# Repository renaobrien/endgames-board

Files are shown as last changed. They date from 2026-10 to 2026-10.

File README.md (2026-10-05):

# Endgames Board

An open-source touchscreen chess board you can print and build at home. It plays your live games from [endgam.es](https://endgam.es) in full color, with your custom piece set on the board.

> Status: early. The reference board is built and paired, and firmware runs on it with over-the-air updates. The case (v0 STLs) is not test-fit yet and has no battery bay. The build guide is a draft.

## How it works

1. The board shows a 6-character pairing code.
2. You enter the code at endgam.es/board/pair while signed in.
3. The board picks up your current game. Tap a piece, tap where it goes.

Your opponent can be on the web, the app, or another board. Games against the in-app AI stay in the app.

## What's in this repo

| Folder | What it holds |
|---|---|
| [`docs/`](docs/) | Build guide |
| [`hardware/`](hardware/) | Printable case files (STL/3MF), source CAD, print settings |
| [`electronics/`](electronics/) | Parts list and wiring |
| [`firmware/`](firmware/) | Code that runs on the board |
| [`protocol/`](protocol/) | The device API the board uses to talk to endgam.es |

## Licenses

- Hardware (case, CAD, wiring, parts list): [CERN-OHL-S v2](LICENSE-HARDWARE)
- Firmware and code: [MIT](LICENSE)
- The Endgames name and logo: see [TRADEMARK.md](TRADEMARK.md)

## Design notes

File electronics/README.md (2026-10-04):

# Electronics

## Parts list (reference build)

| Part | Qty | Notes |
|---|---|---|
| Elecrow CrowPanel Advanced 5" ESP32-P4 HMI (800x480 IPS touch) | 1 | Controller, screen, touch and Wi-Fi in one |
| USB-C cable + 5V/2A power supply | 1 | Power and flashing |
| LiPo battery with PH2.0 plug | optional | For cordless play; the board charges it |

Wiring diagrams get added here if the build needs anything beyond the all-in-one board.

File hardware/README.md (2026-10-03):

# Hardware

Case files for the reference build: STL/3MF for printing, plus source CAD so you can modify it.

Each file gets listed here with its print settings (material, layer height, infill, supports) once it fits the reference board.

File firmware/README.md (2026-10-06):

# Firmware

Runs on the Elecrow CrowPanel Advanced 5" ESP32-P4 (800x480, GT911 touch). ESP-IDF + LVGL 9. Wi-Fi comes through the onboard ESP32-C6 (ESP-Hosted).

**Status:** compiles for the ESP32-P4 with ESP-IDF v5.5.1 (verified 2026-10-04). `main/bsp.c` brings up the screen, touch, backlight and Wi-Fi using the pins and timings from Elecrow's published sources for this board. Runs on the real board; over-the-air releases 0.8.0 to 0.12.0 have shipped and two consoles are paired.

## Known issue: Wi-Fi chip startup on early P4 boards

Boards with ESP32-P4 silicon v1.x (the boot log says `chip revision: v1.3`) can crash in a loop while ESP-Hosted starts the C6 Wi-Fi chip, before `app_main` (`assert failed: vApplicationGetIdleTaskMemory` or `esp_startup_start_app`). It hit the reference board on 2026-10-05 with firmware that had worked the day before. Fixed in 0.11.4 (0.11.5 for the full fix) by keeping ESP-Hosted's transport buffers in PSRAM (`CONFIG_ESP_HOSTED_MEMPOOL_PREFER_SPIRAM`) and running the SDIO link at 20 MHz. PSRAM stays at 200 MHz: at 80 MHz the RGB panel cannot read its frame buffer fast enough and the picture drifts sideways. Background: Elecrow CrowPanel 5" P4 issue #3, esp-hosted #657, esp-hosted-mcu #167. The C6 still runs its factory ESP-Hosted firmware, which is older than the host side; updating it over SDIO is the longer-term fix.

## Layout

| Path | What |
|---|---|
| `main/ui_game.c` | Game screen: 480x480 board, 320 px panel, tap to move, promotion picker, flip, menu |
| `main/ui_screens.c` | Wi-Fi setup, pairing, idle screens |
| `main/chess_pos.c` | FEN parsing, check detection, legal-move lookup. No LVGL |
| `main/api.c` | Device API client (`../protocol/API.md`) |
| `main/pieces_store.c` | Downloads the 12 piece PNGs from `board-pieces` into PSRAM |
| `main/store.c` | Wi-Fi and device token in NVS |
| `main/bsp.c` | Hardware bring-up: power rails, I2C, backlight MCU, 800x480 RGB panel, GT911 touch, Wi-Fi via the C6. The only hardware-specific file |
| `main/theme.h` | Generated colors. Do not edit |
| `main/fonts/` | Generated LVGL fonts (Sora, VT323, Bungee, all OFL) |
| `tools/preview/` | Desktop renderer for the screens |

## Colors and pieces come from the website

- `theme.h` is generated from the website's `src/styles/v2.css` by `npm run board:theme` in the endgames repo. Never hand-copy colors.
- Pieces come from the `board-pieces` endpoint, which resizes the same art the website draws.
- Fonts: `./fonts/build-fonts.sh` converts the TTFs in `fonts/src` (needs Node). OFL license files sit next to them.

## Preview on a desktop

```
cd firmware/tools/preview
./render.sh
```

Needs cmake, a C compiler and git. Writes PNGs to `docs/screenshots/`. The 12 piece PNGs in `tools/preview/pieces/` come from `npm run board:preview-pieces` (default set only).

## Build for the board

```
. $IDF_PATH/export.sh          # ESP-IDF v5.5.x
idf.py set-target esp32p4
idf.py build flash monitor     # board plugged into the UART0 USB-C
```

Versions that build: ESP-IDF v5.5.1, LVGL 9.2.2, esp_lvgl_port 2.6.x (newer esp_lvgl_port needs a newer IDF and LVGL).

Never commit Wi-Fi passwords or the device token. `main/secrets.h` and `.env*` are gitignored.

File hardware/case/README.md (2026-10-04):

# Case v0: flat brick

Two printed parts and four screws. Outer size 138.0 x 84.9 x 22.2 mm.

| File | What | Print |
|---|---|---|
| `case-tray.stl` | Back shell. Holds the board on 4 corner posts. Opening for the lower USB-C port (power), a slot for the power slider extender, microSD, and BOOT/RESET holes in the floor. The upper USB-C (UART0) stays closed: it's next to the slider and only needed for flashing, done with the case open | Floor down, no supports |
| `test-fit-tray.stl` | The tray with most of the floor cut out. Same walls, posts and openings. Print this first to check the USB-C ports, power switch, microSD and screw posts | Floor down, no supports. About 40% less plastic |
| `power-slider-extender.stl` | Clips onto the tiny power slider nub. Its tab sticks out the slot in the case side so you can switch the board on and off | Socket opening up, no supports |
| `case-lid.stl` | Front frame. Window matches the lit screen area, so no black border shows | Face down, no supports |

Hardware: 4 x M3 x 20 mm screws, from the back. They pass through the tray posts and the board's corner holes and bite into the lid's posts.

Source: `brick.py` (Python, trimesh). Change the numbers at the top and re-run to regenerate the STLs.

v0 limits:
- Port and button positions are estimated from a photo of the board with a ruler (about +/- 2 mm). Openings are oversized to allow for that.
- Hole positions are estimated too. Print `../test-fit-plate.stl` first.
- No battery bay yet.

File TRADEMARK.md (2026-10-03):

# Trademark

The code and hardware in this repo are open. The Endgames name and logo are not covered by those licenses.

You can:

- Build boards from this repo for yourself or as gifts.
- Modify the design and share your version.
- Say your board is "compatible with Endgames" or "based on the Endgames Board."

You can't, without written permission:

- Sell boards, kits, or cases under the Endgames name or logo.
- Use the Endgames name or logo in a way that suggests your product is official.

Questions: open an issue.

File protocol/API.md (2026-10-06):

# Endgames Board Device API, v1

Base URL: `https://endgam.es/.netlify/functions`

Every response carries the header `X-Endgames-Board-Api: 1`. Bodies are JSON.

## Pairing

The board shows a code. The owner types it on endgam.es. The board then receives a device token it keeps in flash.

### 1. Start: `POST /board-pair-start`

No auth, no body.

```json
200 { "code": "K7XQ2M", "pollSecret": "egp_...", "expiresAt": "2026-10-03T20:00:00Z", "claimUrl": "https://endgam.es/board/pair?code=K7XQ2M" }
429 { "error": "Too many pairing attempts" }
```

Show `code` as text and `claimUrl` as a QR code (and as text). The URL carries the code, so scanning it prefills the pairing page. Keep `pollSecret` private. Codes expire after 10 minutes.

### 2. Owner claims the code

The owner signs in at endgam.es and enters the code. The board does nothing in this step.

### 3. Poll: `POST /board-pair-poll`

```json
{ "pollSecret": "egp_..." }
```

```json
202 { "status": "pending" }
200 { "status": "paired", "deviceToken": "egb_...", "deviceId": "uuid" }
410 { "error": "Pairing expired. Start again." }
```

Poll every 3 seconds. `deviceToken` is returned once. Store it, then stop polling.

## Playing

Send the device token on every call:

```
Authorization: Bearer egb_...
```

A `401` means the token was revoked or is unknown. Wipe it and start pairing again.

### Get the current game: `GET /board-game`

Optional query: `?gameId=uuid` to fetch a specific game (any status).

```json
200 {
  "apiVersion": 1,
  "game": {
    "id": "uuid",
    "fen": "rnbqkbnr/pppppppp/8/8/4P3/8/PPPP1PPP/RNBQKBNR b KQkq - 0 1",
    "yourColor": "white",
    "turn": "black",
    "yourTurn": false,
    "status": "IN_PROGRESS",
    "moveCount": 1,
    "lastMove": { "from": "e2", "to": "e4", "san": "e4" },
    "moves": ["e4"],
    "legalMoves": [],
    "timeControl": "1d",
    "moveDeadline": "2026-10-07T19:30:00Z",
    "clock": null,
    "endReason": null,
    "opponent": { "name": "magnus_fan", "isAi": false, "difficulty": null, "pfpUrl": "https://.../avatar.png" },
    "updatedAt": "2026-10-03T19:30:00Z"
  }
}
```

`moves` is every move so far in SAN, oldest first (up to 500), for the move list.

**Time per move.** Games against people have one deadline per move. `timeControl` is `"1d"`, `"3d"` or `"1w"` (1 day, 3 days, 1 week per move), or `null` for a computer game. `moveDeadline` is the moment the player on the move loses on time, as an ISO 8601 UTC string. It is `null` when there is no deadline: computer games, finished games, and games started with a live clock (below). Every move resets the deadline for the player who moves next, so after your move `moveDeadline` is your opponent's, and the reverse. `yourTurn` tells you whose it is.

Show the time left in words, rounded down: `23 h left`, `2 days left`, `45 min left`; `1 day left` and `1 h left` in the singular. Count down to `moveDeadline` using the `Date` response header as "now" (or the device clock if it is set from the network): the deadline is a server time, and a day-long deadline tolerates a few minutes of skew. When 2 hours or less are left on your move, show a banner (the console has no speaker, so visual only). When the deadline passes, call `board-game` right away: the server settles the game and the response shows the result. The server gives a mover 1 second of grace for network delay.

If a first move is missed (white never moves, or black never replies to white's first move) the game ends as `ABANDONED` with no rating change. After that, a missed deadline is a loss on time, unless the other player cannot possibly checkmate, which is a draw.

**Live clocks (retired).** Games started before time per move existed carry a live clock and finish under their old rules: `timeControl` is one of `3+2`, `5+0`, `10+0`, `15+10`, `moveDeadline` is `null`, and `clock` is `{ "incrementMs", "yourMs", "opponentMs", "running" }`: the time each side has left at the moment of the response, with `running` set to `"you"`, `"opponent"` or `null`. Count down locally and replace the numbers on every response. No new game gets a live clock, so a firmware that only shows time per move can show nothing extra for these games, or keep its clock code until none are left.

`endReason` is `null` while the game is in progress. Afterwards it is one of `checkmate`, `draw` (stalemate and other draws), `resign`, `timeout`, `abandoned`. Games finished before clocks existed have `null`. A game lost on its deadline reads `timeout`.

`opponent.isAi` is true in games against the computer, with `difficulty` set (`beginner`, `intermediate`, `advanced`, `expert`; computer games started on the website before difficulty was stored read as `intermediate`). For people, `difficulty` is `null`.

`game` is `null` when there is nothing to play. `status` is one of `IN_PROGRESS`, `WHITE_WON`, `BLACK_WON`, `DRAW`, `ABANDONED`.

`legalMoves` lists your moves in UCI form (`e2e4`, `e7e8q`) when it's your turn, and is empty otherwise. Use it to highlight squares after a tap.

Polling: every 10 seconds while waiting for the opponent (every 5 seconds in a timed game), every 60 seconds when idle. Redraw only when `moveCount` or `status` changes.

### Make a move: `POST /board-move`

```json
{ "gameId": "uuid", "from": "e7", "to": "e5", "moveCount": 1 }
```

Add `"promotion": "q"` (`q`, `r`, `b`, or `n`) when a pawn reaches the last rank. `moveCount` is the value from your last `board-game` response.

```json
200 { "apiVersion": 1, "game": { ... } }
409 { "error": "Board is out of date", "apiVersion": 1, "game": { ... } }
409 { "error": "Not your turn", ... }
409 { "error": "Game is over", ... }
422 { "error": "Illegal move", ... }
```

Every `409` and `422` includes the current `game`. Redraw from it.

The server checks legality on every move. `legalMoves` is there so the board can show where a piece can go.

### Get piece images: `GET /board-pieces`

Optional query: `?gameId=uuid` to use the piece set you have in that game. Without it, the board gets your active set, or the default set if you have none.

```json
200 {
  "apiVersion": 1,
  "set": { "id": "uuid-or-default-hash", "name": "My set", "kind": "custom" },
  "size": 60,
  "pieces": {
    "wk": "https://.../board/<set>/wk.png", "bk": "https://.../board/<set>/bk.png",
    "wq": "...", "bq": "...", "wr": "...", "br": "...",
    "wb": "...", "bb": "...", "wn": "...", "bn": "...", "wp": "...", "bp": "..."
  }
}
502 { "error": "Could not prepare piece images" }
```

Twelve PNGs, 60x60, transparent background. Keys are color (`w`/`b`) plus piece (`k q r b n p`). Black pieces match the website: the same art darkened with a thin light halo. The URLs are public and permanent per set, so download once per set and cache on flash or SD. The first call for a set can take a few seconds while the server resizes and caches the images. Fetch again when `set.id` changes.

## Home, new games and sets (v1 additions)

The board is a full Endgames client: it starts games, lists them, and switches piece sets, the same as the website. These are additive v1 endpoints.

### Home screen: `GET /board-home`

One call for the home screen.

```json
200 {
  "apiVersion": 1,
  "profile": { "name": "deltajuliet", "pfpUrl": "https://.../avatar.png", "elo": 1240, "ranked": true,
               "wins": 31, "losses": 18, "draws": 3, "winRate": 60 },
  "games": [
    {
      "id": "uuid",
      "opponent": { "name": "queenbee", "isAi": false, "difficulty": null, "pfpUrl": "https://.../avatar.png" },
      "yourColor": "white",
      "yourTurn": true,
      "status": "IN_PROGRESS",
      "moveCount": 14,
      "timeControl": "1d",
      "moveDeadline": "2026-10-05T19:30:00Z",
      "yourMs": null,
      "opponentMs": null,
      "running": null,
      "updatedAt": "2026-10-04T19:30:00Z"
    }
  ],
  "incomingChallenges": [ { "id": "uuid", "from": { "name": "queenbee", "elo": 1820, "pfpUrl": "https://.../avatar.png" } } ],
  "activeSetId": "uuid-or-default",
  "sets": [ { "id": "uuid-or-default", "name": "Default", "kind": "default", "missing": false,
              "preview": { "wk": "https://.../wk.png", "wn": "https://.../wn.png" } } ]
}
```

Each list item carries `timeControl` and `moveDeadline` (same meaning as in `board-game`; both `null` for a computer game). `yourMs`, `opponentMs` and `running` are set only for games started with a live clock before time per move existed (same meaning as `clock` in `board-game`) and are `null` otherwise. Show "Your turn" or "Their turn", and the time left on the move next to it.

`games` holds your in-progress games (against people and the computer), your-turn first, then most recently updated, up to 20. You can have at most 20 in progress; `board-new-game` returns `429` above that. `incomingChallenges` lists direct challenges waiting for your answer (see `board-challenge-respond`). `sets` lists the built-in set plus sets you made. A set with `"missing": true` has pieces that no longer load (the images were saved with a link that expired): its `preview` is `null`, show "Pieces missing", and don't offer it as a choice (`board-set` answers `409` for it). It can still be renamed or deleted. `activeSetId` is never a missing set: if the active set's pieces are gone it reads `"default"`. Treat a missing `missing` field as `false`. `elo` is `null` and `ranked` false before the first ranked game.

`profile.wins`, `losses` and `draws` count your finished games. `winRate` is wins over all finished games as a whole percent (the number the website's You screen shows), and `null` before your first finished game, when the three counts are `0`. Older servers leave all four out: treat a missing field as no stats.

`pfpUrl` is the player's profile picture: a public https link to a 256x256 PNG for pictures set on the website (Account, Profile picture). It is `null` when the player has not set one, and always `null` for the computer. Old accounts may hold a picture from another site (often a JPEG), so check the content type before decoding. Cache by URL: a new picture gets a new URL.

### Start a game: `POST /board-new-game`

Against the computer:

```json
{ "mode": "ai", "difficulty": "beginner", "first": "me" }
```

`difficulty` is `beginner`, `intermediate`, `advanced` or `expert` (shown as Easy, Medium, Hard, Expert). `first` is `me`, `computer` or `random` (who moves first). The older `color` field (`white`, `black`, `random`) is still accepted. Returns `200 { "apiVersion": 1, "game": { ... } }` in the `board-game` shape. If the computer plays white, its first move is already made.

Challenge a friend:

```json
{ "mode": "challenge", "color": "random" }
```

Creates an open challenge with your active set. `color` is the color you play (`random` picks one). Add `"timeControl"`: `"1d"` (default), `"3d"` or `"1w"`, the time each player has per move. Returns:

```json
200 { "apiVersion": 1, "challenge": { "id": "uuid", "url": "https://endgam.es/?challenge=uuid", "expiresAt": "..." } }
```

The board shows `url` as a QR. When someone accepts, the game appears in `board-home` and `board-game`.

Challenge a specific player (find them with `board-users`):

```json
{ "mode": "challenge", "opponentId": "uuid", "first": "me", "timeControl": "3d" }
```

`timeControl` is `"1d"`, `"3d"` or `"1w"`, and `"1d"` when left out. Anything else is `400`. It is also `400` for computer games, which have no deadline. For consoles on older firmware, the old values (`3+2`, `5+0`, `10+0`, `15+10`, `"untimed"`, `null`) are accepted and become `"1d"`.

`first` is `me`, `computer` or `random`; here `computer` means the other player moves first. Returns:

```json
200 { "apiVersion": 1, "challenge": { "id": "uuid", "opponent": "queenbee", "expiresAt": "..." } }
```

`404` if the player does not exist or is the computer, `400` if you challenge yourself, `409` if you already have a pending challenge with that player. The other player sees it in their `board-home` `incomingChallenges` (and on the website's Play tab). Challenges expire after 48 hours.

### Find a player: `GET /board-users?q=`

Username search for "Challenge a player". `q` needs at least 3 characters (shorter returns an empty list).

```json
200 { "apiVersion": 1, "users": [ { "id": "uuid", "name": "queenbee", "elo": 1820 } ] }
```

At most 10, highest rating first. Excludes you and the computer.

### Answer a challenge: `POST /board-challenge-respond`

```json
{ "id": "challenge-uuid", "accept": true }
```

Accept returns `200 { "apiVersion": 1, "game": { ... } }` in the `board-game` shape. Decline returns `200 { "apiVersion": 1, "declined": true }`. Only the challenged player can respond: anything else is `404`. `409` means the challenge already expired, was answered, or was withdrawn: refresh `board-home`.

### Quick match: `POST` and `GET /board-quick-match`

Pairs you with the next waiting player. Every quick match is 1 day per move, so there is nothing to pick. A `timeControl` in the body is ignored (consoles on older firmware may still send one).

```json
POST { "action": "join" }    or    { "action": "cancel" }
```

Both `POST` and `GET` return the same shape:

```json
200 { "apiVersion": 1, "status": "waiting" }
200 { "apiVersion": 1, "status": "matched", "game": { ... } }
200 { "apiVersion": 1, "status": "idle" }
```

`join` pairs you with the oldest waiting player right away (`matched`), or queues you (`waiting`). Poll `GET` every 3 seconds while waiting. The first `GET` that returns `matched` delivers the `game` once and clears your queue row, so the next poll says `idle`. Queue entries last 5 minutes (then `idle`). Send `cancel` when the player backs out.

### Games against the computer

`board-game` and `board-game?gameId=` include computer games. After you move with `board-move`, the server makes the computer's reply before responding, so the returned `game` already includes it (or, if that takes longer than the request allows, the reply appears on the next `board-game` poll). Difficulty matches the website.

`sets[].preview` holds the white king and knight PNGs (the same 60x60 images `board-pieces` serves for that set) for the Sets tab.

### Leaderboard: `GET /board-leaderboard`

The same ranking the website shows, top 50.

```json
200 {
  "apiVersion": 1,
  "entries": [ { "rank": 1, "name": "queenbee", "elo": 1820, "isYou": false } ],
  "you": { "rank": 42, "elo": 1240 }
}
```

`you` is `null` before your first ranked game.

### Make a set

The board has no camera, so its Make tab shows a QR for `https://endgam.es/make`, which opens the website's Make tab (after sign-in) on the phone. New sets show up in `board-home`.

### Resign: `POST /board-resign`

```json
{ "gameId": "uuid" }
```

Returns the finished `game`. Resigning a game that's already over returns `409`.

### Switch piece set: `POST /board-set`

```json
{ "setId": "uuid-or-default" }
```

Sets your active set (the same one the website uses). `board-pieces` then returns it. `404` if the set doesn't exist or is deleted; `409` `{ "error": "Pieces missing" }` if the set's pieces no longer load (see `missing` in `board-home`).

### Rename or delete a set: `POST /board-set-edit`

```json
{ "setId": "uuid", "action": "rename", "name": "Vaporwave Rena" }
{ "setId": "uuid", "action": "delete" }
```

Only your own sets. `"default"` can't be edited.

- `rename`: `name` is trimmed, 1 to 32 characters.
- `delete`: hides the set (`is_hidden = true`), the same as deleting on the website, so it can be restored there. If it was your active set, your active set goes back to the default.

Returns `200 { "ok": true, "activeSetId": "uuid-or-default" }`. `404` if the set doesn't exist, is already deleted, or isn't yours. `400` for a bad body or name.

## Versioning

Breaking changes get a new version number and run alongside the old one for at least 6 months. Adding a new field doesn't count as breaking, so ignore fields you don't recognize.

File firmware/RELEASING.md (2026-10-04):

# Releasing board firmware

Boards check https://endgam.es/firmware/board.json at startup and every 6 hours between games.
If the version there is newer than theirs, they download the update, restart into it, and keep it
once it gets back online. If the new version crashes or can't get online, the board goes back to
the previous version on its next restart.

1. Bump the version
   - In `firmware/CMakeLists.txt`, raise `PROJECT_VER` (for example 0.8.0 to 0.9.0).
2. Build
   - `idf.py build`
3. Publish the update file
   - Copy `build/endgames_board.bin` to the Endgames site as `public/firmware/endgames-board-<version>.bin`.
4. Point boards at it
   - Update `public/firmware/board.json`:
     `{"version": "<version>", "url": "https://endgam.es/firmware/endgames-board-<version>.bin"}`
5. Deploy the site
   - Boards pick it up within 6 hours, or right away after a restart.

The USB flasher file (full image at 0x0) is made with
`python -m esptool --chip esp32p4 merge_bin -o endgames-board-v<version>.bin "@flash_args"` from `build/`.
Only needed for first installs; everything after that updates over Wi-Fi.

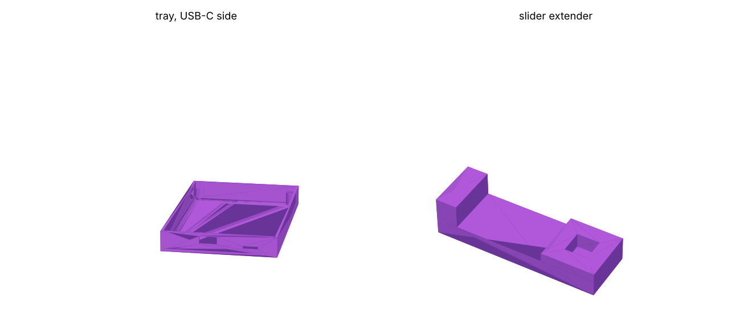
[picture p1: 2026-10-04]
hardware/case/slider-preview.png

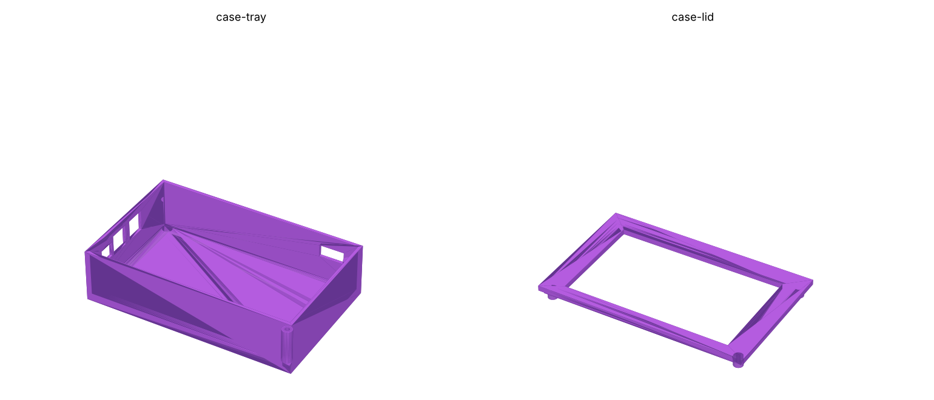
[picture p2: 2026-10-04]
hardware/case/case-preview.png

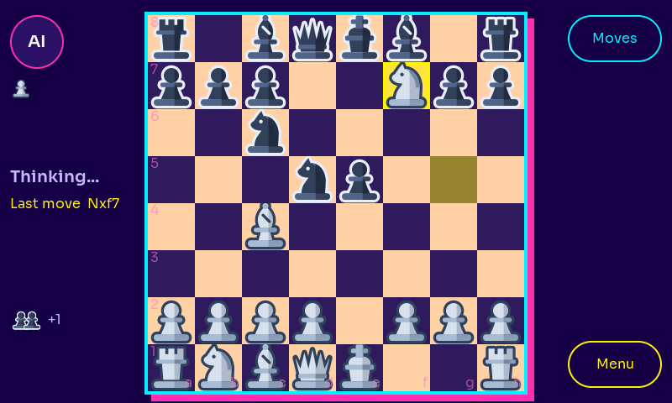
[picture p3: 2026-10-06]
docs/screenshots/board-game.png

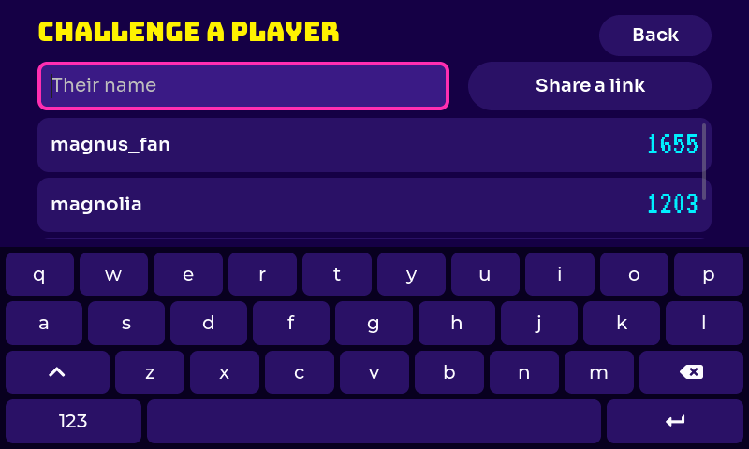
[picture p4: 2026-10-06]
docs/screenshots/board-find.png

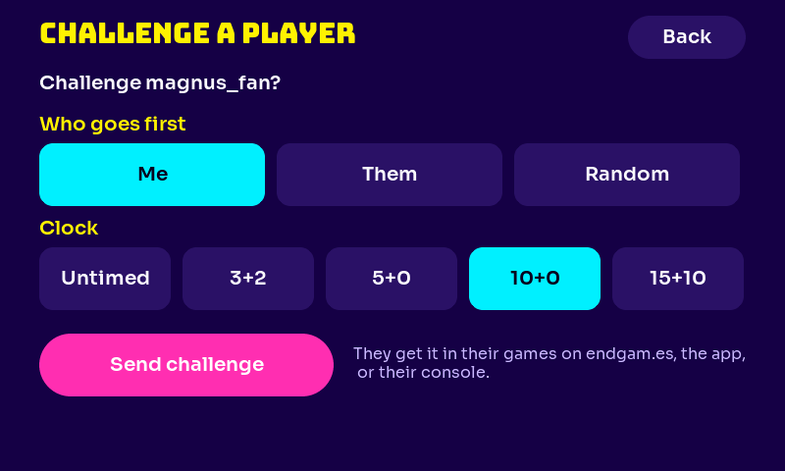
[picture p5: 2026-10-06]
docs/screenshots/board-find-confirm.png

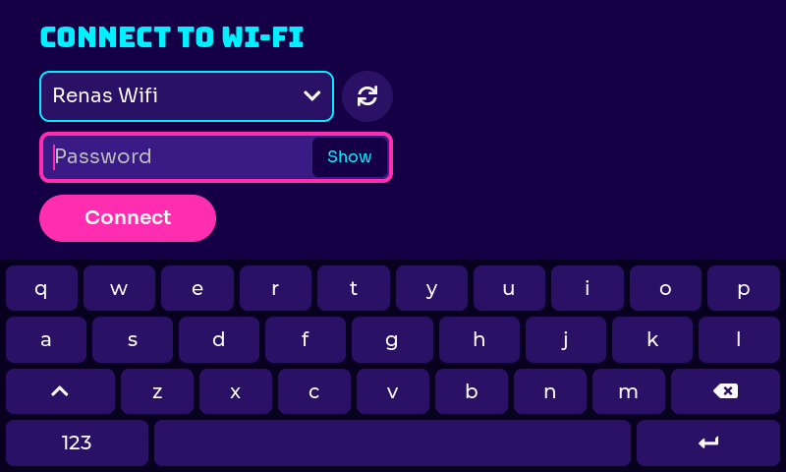
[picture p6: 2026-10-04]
docs/screenshots/board-wifi.png

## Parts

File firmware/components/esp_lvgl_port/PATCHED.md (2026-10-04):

# esp_lvgl_port 2.6.3, patched for Endgames

Upstream 2.6.3 only enables RGB panels on ESP32-S3 (`lvgl_port_add_disp_rgb` fails on the P4 with
"RGB is supported only on ESP32S3"). Elecrow ships the same kind of patch in their CrowPanel P4 factory code.

Change: the S3-only `#if` guards for the RGB header, the RGB vsync/bounce callback and
`lvgl_port_add_disp_rgb` also accept `CONFIG_IDF_TARGET_ESP32P4` (src/lvgl9/esp_lvgl_port_disp.c).
The avoid_tearing frame-buffer path is NOT patched (it calls the MIPI-DSI API on P4), so keep avoid_tearing off.
License: Apache-2.0 (upstream), see license.txt.

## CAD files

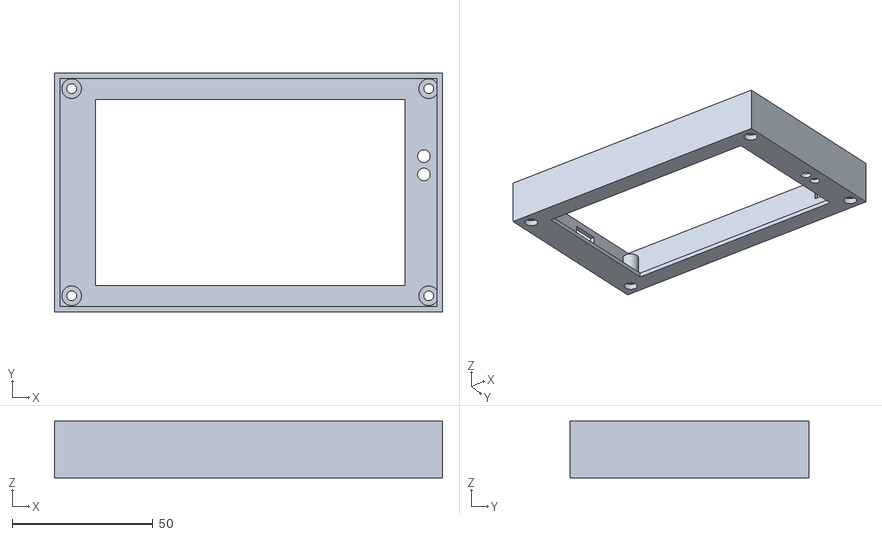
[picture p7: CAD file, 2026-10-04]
hardware/case/test-fit-tray.stl
138.0 x 84.9 x 20.2

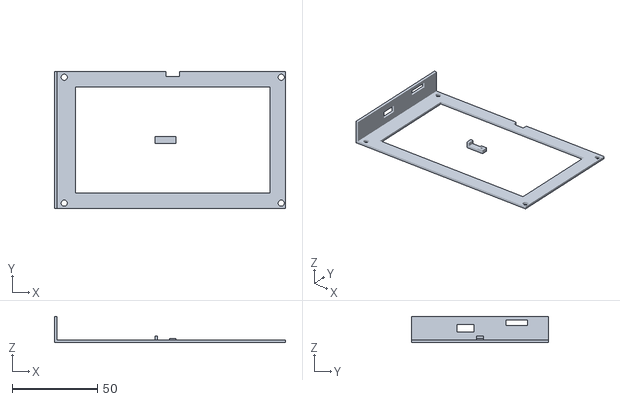
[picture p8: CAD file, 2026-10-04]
hardware/template.stl
135.2 x 80.1 x 15.5

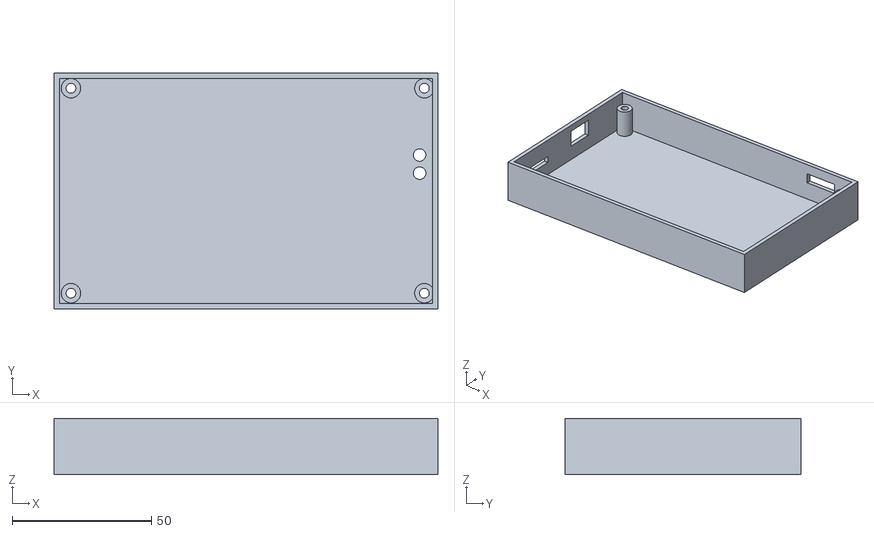
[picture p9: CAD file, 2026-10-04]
hardware/case/case-tray.stl
138.0 x 84.9 x 20.2

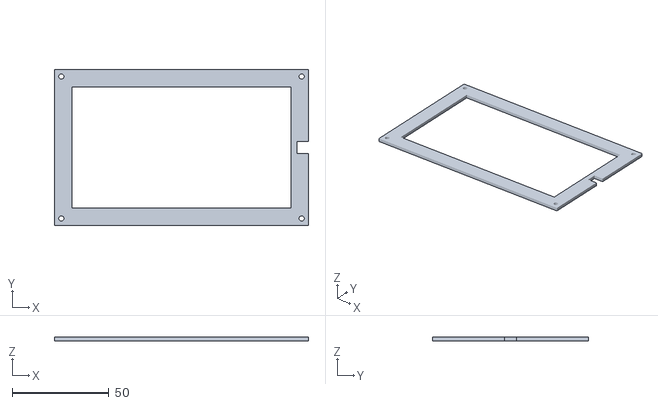
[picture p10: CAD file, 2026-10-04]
hardware/test-fit-plate.stl
131.0 x 80.2 x 2.00

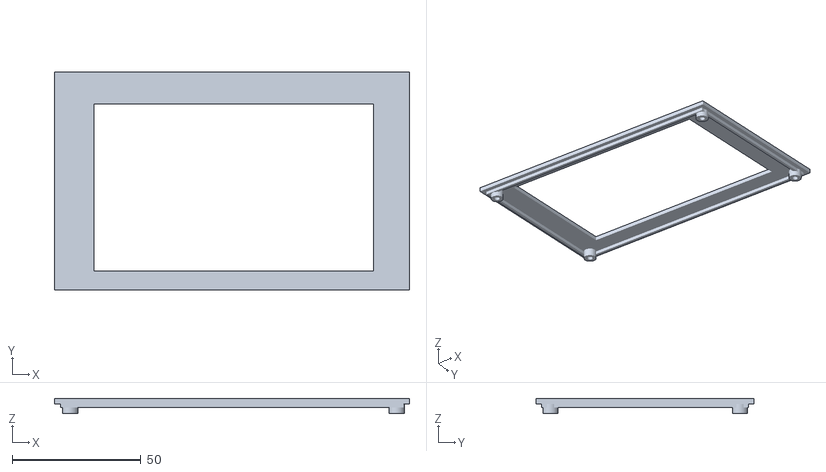
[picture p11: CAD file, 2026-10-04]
hardware/case/case-lid.stl
138.0 x 84.9 x 5.70

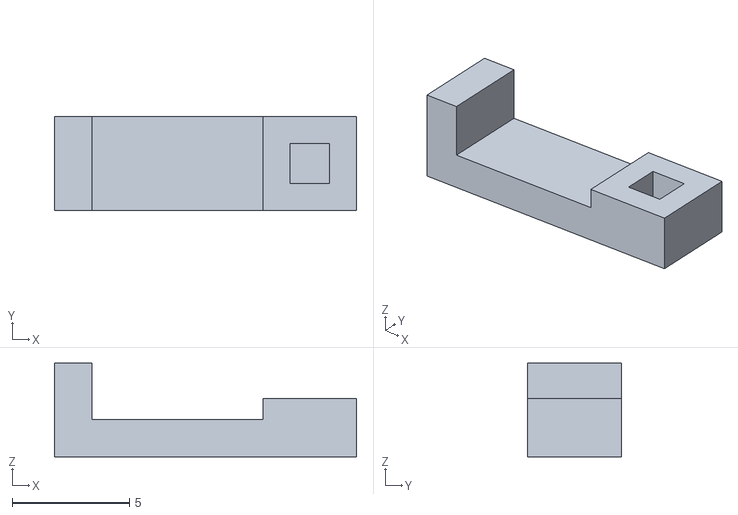
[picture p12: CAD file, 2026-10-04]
hardware/case/power-slider-extender.stl
12.9 x 4.00 x 4.00

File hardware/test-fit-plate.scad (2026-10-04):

// Endgames Board: test-fit plate for the CrowPanel Advanced 5" (ESP32-P4).
// Print it, lay the board on it face up, and check all 4 holes line up.
// Edit the numbers below if they don't, then the case uses the corrected values.
L = 131;       // board length, mm
W = 80.2;      // board width, mm (caliper)
T = 2;         // plate thickness
HOLE_D = 2.7;  // clearance for M2.5
HOLE_IN = 3.5; // hole center from each edge (estimated from photo)
BORDER = 9;    // frame width
NOTCH = 6;     // notch marks the USB-C edge

difference() {
  cube([L, W, T]);
  translate([BORDER, BORDER, -1]) cube([L - 2*BORDER, W - 2*BORDER, T + 2]);
  for (x = [HOLE_IN, L - HOLE_IN], y = [HOLE_IN, W - HOLE_IN])
    translate([x, y, -1]) cylinder(d = HOLE_D, h = T + 2, $fn = 40);
  translate([L - NOTCH/2, W/2 - NOTCH/2, -1]) cube([NOTCH, NOTCH, T + 2]);
}

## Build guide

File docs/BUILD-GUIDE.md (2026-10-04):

# Build Guide

Build a touchscreen chess board that plays your live games from [endgam.es](https://endgam.es), with your own piece set on it.

Each step says what I used, then what changes if you use something else.

> **Status:** the case and parts below are being test-printed on the reference board. The firmware is written but not yet running on real hardware. This guide gets updated as each part is confirmed.

## What you need

| Part | What I used | Notes |
|---|---|---|
| Screen + controller | Elecrow CrowPanel Advanced 5" ESP32-P4 HMI (SKU DHE04005D), 800x480 IPS touch, about $43 | Screen, touch, Wi-Fi and USB-C all on one board. No wiring |
| Power | USB-C cable and a 5V/2A USB power adapter | Plugs into the board's lower USB-C port |
| Screws | 4 x M3 x 20 mm | Hold the case together through the board's corner holes |
| Printer + filament | Any FDM printer, PLA | Nothing needs supports |
| Computer | Mac, Windows or Linux with a USB-C cable | Only for installing the firmware once |

**If you use something else:**

- **The 7" CrowPanel Advanced (ESP32-P4, 1024x600):** same chip family, so the firmware should carry over with a new screen layout. The case needs new dimensions (see `hardware/case/brick.py`).
- **An ESP32-S3 CrowPanel or another ESP32 touchscreen:** works with a different display and touch setup in `firmware/main/bsp.c`. The case won't fit.
- **A battery:** the board has a battery connector with charging, but this case has no battery space yet.

## 1. Print the test template first

The template is a thin frame that checks the board lines up with the case before you print the whole thing. It also prints the power slider extender.

1. Print `hardware/template.stl`.
   - Flat, no supports.
2. Push the extender's square socket onto the board's power switch nub.
   - The switch is labeled POWER, on the back, next to the USB-C ports.
3. Lay the board screen down on the template.
   - USB-C edge against the template's wall.
   - The edge with the UART1 and I2C connectors goes on the side with the notch.
4. Check:
   - The 4 corner holes line up with the board's holes.
   - The lower USB-C port shows through its window.
   - The extender's tab sticks out through the long slot and switches the board on and off.

**If something is off:** change the numbers at the top of `hardware/template.py` and `hardware/case/brick.py`, then re-run them to regenerate the files. Measurements I used are in `hardware/MEASUREMENTS.md`.

## 2. Install the firmware

Do this with the board out of the case. The case keeps the flashing port covered.

### Easiest: flash from the browser (no installs)

1. Get the firmware file.
   - Download `endgames-board-vX.Y.bin` from the repo's Releases page.
2. Plug the board into your computer.
   - Use the upper USB-C port, labeled UART0 (next to the power switch).
   - Slide the power switch on.
3. Open the web flasher in Chrome or Edge.
   - Go to https://espressif.github.io/esptool-js/
   - Safari won't work.
4. Connect.
   - Baudrate: 460800.
   - Click Connect and pick the USB serial port that appears.
   - The log should say ESP32-P4. Note the chip revision it prints.
5. Flash.
   - Flash Address: `0x0`.
   - File: the `.bin` you downloaded.
   - Click Program and wait for it to finish.
6. Restart the board.
   - Tap RESET on the back, or slide the power switch off and on.
   - The screen should show the Wi-Fi setup screen.

### From source

1. Install ESP-IDF on your computer.
   - Follow Espressif's ESP-IDF install guide for your system.
2. Plug the board into your computer.
   - Use the upper USB-C port, labeled UART0.
3. Build and flash.
   - In a terminal, from the `firmware` folder:
   - `idf.py set-target esp32p4`
   - `idf.py build flash monitor`
   - To mount the screen upside down: `idf.py menuconfig`, then Endgames board, then Rotate 180.
4. Watch the screen.
   - It should show the Wi-Fi setup screen.

**If it won't flash:** hold the BOOT button on the back, tap RESET, release BOOT, then flash again.

## 3. Print and assemble the case

The case is a flat brick, 138 x 85 x 22 mm, in two parts.

1. Print the parts.
   - `hardware/case/case-tray.stl`: floor down, no supports.
   - `hardware/case/case-lid.stl`: face down, no supports.
   - `hardware/case/power-slider-extender.stl` (or reuse the one from the template print).
2. Fit the extender.
   - Push it onto the power switch nub.
   - Slide the switch to ON.
3. Put the board in the tray.
   - Screen up.
   - The extender's tab goes through the slot in the side wall.
4. Close it.
   - Lay the lid on top.
   - Screw the 4 M3 x 20 mm screws in from the back.
5. Plug in power.
   - USB-C cable into the port on the side.

## 4. Connect and pair

1. Connect to Wi-Fi.
   - Follow the Wi-Fi setup screen on the board.
2. Pair it with your account.
   - The board shows a 6-letter code.
   - On your phone or computer, go to endgam.es/board/pair and sign in.
   - Type the code.
3. Play.
   - The board picks up your current game.
   - Tap a piece, then tap where it goes.

You can switch between the board and the website mid-game. Both show the same game.

## Troubleshooting

| Problem | Fix |
|---|---|
| Board shows "No game in progress" | Start a game on endgam.es. Games against the computer only play on the website |
| Pairing code expired | Codes last 10 minutes. Turn the board off and on for a new one |
| Board stopped showing your games | It was unpaired. It goes back to the pairing screen; pair again |
| Moves take a few seconds to appear | The board checks for new moves every few seconds |

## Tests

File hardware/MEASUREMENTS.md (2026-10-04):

# Reference board measurements

**Source of truth: Elecrow's own PCB design file** (`ESP32-P4 Display 5.0 inch V1.0.brd`, in Elecrow's GitHub repo for this board). Numbers below that came from it are marked "Eagle". Caliper and photo numbers were used before the file was found.

| What (Eagle) | Value |
|---|---|
| Board outline | 132.0 x 80.12 mm |
| Corner holes | 3.39 mm (M3). Caliper: 127.0 x 73.66 mm center to center, 3.33 mm from the UART1/I2C edge. (Eagle said 126.0 x 74.3, wrong) |
| USB-C UART0 (J1) center | 31.6 mm from the UART1/I2C edge |
| USB-C USB2.0 (J16) center | 48.6 mm from the UART1/I2C edge |
| Power slider (SW1) center | 18.6 mm from the UART1/I2C edge, 4.8 mm in from the USB-C edge, footprint 9.2 x 3.6 mm |
| BOOT / RESET (K3 / K4) | 4.2 mm in from the opposite short edge, 46.5 / 53.0 mm from the UART1/I2C edge |
| 2x8 header (J7) | center 55.6 mm along, 6.6 mm from the microSD edge |

Note: caliper on 2026-10-04 read the board holes as 3.39 mm (0.1335"). M3 screws. Case tray holes 3.5 mm clearance, lid posts 2.6 mm pilot.

## Earlier hand measurements

Board: Elecrow CrowPanel Advanced 5" ESP32-P4 HMI, SKU DHE04005D, PCB marked "ESP32 P4-Advance HMI Display 5.0 V1.0".

Measured by hand with calipers (2026-10-04) unless marked otherwise. "Back view" = looking at the PCB side, screen face down.

| What | Value | Source |
|---|---|---|
| Length (long edge) | 131 mm (5.16") | Elecrow spec; caliper photo agrees within about 1 mm |
| Width (short edge) | 80.2 mm (3.158") | Caliper |
| Thickness, screen + PCB | 5.1 mm (0.20") | Caliper |
| Thickness, deepest part (no battery) | 16.5 mm (0.65") | Caliper. On the microSD edge; from the photo this is the 2x8 pin header |
| Visible screen glass, long side | 119 mm (4.7") | Caliper |
| PCB lip around the glass | about 5 mm (0.2") per side | Caliper |
| Screen glass, short side | 75.8 mm (2.9845") | Caliper |
| Black border on the glass, top | 2.5 mm (0.1") | Caliper |
| Black border on the glass, bottom | 7.6 mm (0.3") | Caliper. On the microSD edge. Wider side is where the display's ribbon cable enters |
| Black border on the glass, left and right | 5.1 mm (0.2") each | Caliper |
| Lit display area (derived) | about 109 x 66 mm | Glass minus borders. Matches Elecrow's 108 x 65 mm spec |
| Mounting holes | 4, one per corner, on the PCB lip outside the glass | Visual |
| Hole diameter | 3.39 mm (0.1335"), M3 | Caliper |
| Hole center from edges | about 3.5 mm from both edges | Estimated from photo. Confirm with the test-fit plate |

## From the side photo of the USB-C edge

- Order along that edge, from the 5V-in end: white UART3-IN connector, USB-C (USB2.0), USB-C (UART0), power slider.
- USB-C shells sit about 1.8 mm off the board and overhang the edge about 1 mm. The case and template allow 1.6 mm on that side.
- The white UART3-IN connector stays inside the case (Rena confirmed it does not stick out past the edge).

## Things on the edges (back view, USB ports on the right)

| Edge | Item | Case needs |
|---|---|---|
| Right | USB-C "UART0" (upper), used for flashing/serial | Cutout |
| Right | USB-C "USB2.0" (lower) | Cutout |
| Right | UART3-IN connector (5V in), below the USB ports | Cutout or leave closed |
| Top right | POWER slide switch | Cutout so it can be switched |
| Bottom left | microSD (TF) slot | Cutout, optional |
| Left | BOOT and RESET buttons (on the back, near the left edge) | Access holes, needed for flashing |
| Inset, bottom | BAT, SPKR connectors | No cutout; cable routes inside the case |
| Front | Status LEDs CHG/PWR near the USB ports | Optional light pipe |

## Front window

The lit area is not centered top to bottom: it sits about 2.5 mm away from the microSD edge (toward the UART1/I2C edge). The case's front window follows the lit area, not the glass, or one edge shows a fat black strip.

## Open

- Hole-center positions: print the test-fit plate (`hardware/test-fit-plate.scad`) and check the screws line up before printing the full case.

## Power slider (caliper)

- Switch body 7.62 x 3.68 x 5.13 mm (0.300 x 0.145 x 0.202"), set 3.49 mm (0.1375") in from the USB-C edge.
- Nub 1.5 mm (0.059") square, pointing straight out from the back. Its tip is 5.1 mm (0.202") from the board (confirmed by side photo).
- Travel not measured; the case slot allows the most the nub can move inside its body (6.1 mm).
- Handled with a printed extender (`case/power-slider-extender.stl`). The button wiring below is no longer needed.

## Power button (not used)

- Push button (red + black wires, white cap) between header pin **IO29** and **GND**. Firmware: internal pull-up, press = backlight off + light sleep, press again = wake.
- Header pins free for general use: IO29, IO30, IO31. Not free: IO26 (SPI clock), IO32 (resets the Wi-Fi chip), IO47/IO48 (shared with UART1 / wireless socket).
- Power slider stays ON permanently.
- No-solder wiring: female Dupont jumper leads + Wago 221-412 lever connectors.
- Source: espboards.dev pinout for the CrowPanel Advance 5.0 (ESP32-P4).

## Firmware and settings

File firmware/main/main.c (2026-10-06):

/* SPDX-License-Identifier: MIT */
/* Endgames Board firmware: boot, Wi-Fi, pairing, then play.
 * One network task owns all HTTP. The UI runs in LVGL's task; every LVGL call from the network
 * task is wrapped in lvgl_port_lock / unlock. */
#include "api.h"
#include "bsp.h"
#include "esp_heap_caps.h"
#include "esp_log.h"
#include "esp_lvgl_port.h"
#include "freertos/FreeRTOS.h"
#include "freertos/task.h"
#include "nvs_flash.h"
#include "ota.h"
#include "fonts.h"
#include "theme_rt.h"
#include "pieces_store.h"
#include "store.h"
#include "esp_system.h"
#include "ui_game.h"
#include "ui_screens.h"
#include <string.h>

#if __has_include("secrets.h")
#include "secrets.h"
#endif

static const char *TAG = "eg";

static char token[96];
static lv_obj_t *scr_boot, *scr_wifi, *scr_pair, *scr_home, *scr_ai, *scr_chal, *scr_qm, *scr_find, *scr_sets, *scr_make, *scr_rank, *scr_you, *scr_game;
static eg_rank_t rank;
static eg_home_t home;                  /* last board-home result */
static eg_game_t cur;
static bool have_game;
static volatile bool want_wifi_screen, want_wifi_back;


static void boot_status(const char *msg)
{
    lvgl_port_lock(0);
    if (scr_boot && lv_screen_active() == scr_boot) eg_boot_set_status(scr_boot, msg);
    lvgl_port_unlock();
}

static void show(lv_obj_t *s)
{
    lvgl_port_lock(0);
    lv_screen_load(s);
    lvgl_port_unlock();
}

/* Main screens (pairing, idle, game). If the Wi-Fi screen is open on top, remember it for Back instead. */
static lv_obj_t *behind;
static bool wifi_open;
static void show_main(lv_obj_t *s)
{
    behind = s;
    if (!wifi_open) show(s);
}

/* ---------- UI callbacks (run in LVGL task) ---------- */

/* Connect runs in the network task (it blocks up to 20 s); the UI only hands over the credentials. */
static char want_ssid[33], want_pass[65];
static volatile bool creds_pending;

static void on_wifi_connect(const char *ssid, const char *pass)
{
    strncpy(want_ssid, ssid, sizeof want_ssid - 1);
    want_ssid[sizeof want_ssid - 1] = 0;
    strncpy(want_pass, pass, sizeof want_pass - 1);
    want_pass[sizeof want_pass - 1] = 0;
    creds_pending = true;
}

static void on_move(const char *from, const char *to, char promo)
{
    /* Hand off to the network task via a small queue-free flag set: moves are rare, so use a one-slot mailbox. */
    extern void eg_net_submit_move(const char *, const char *, char);
    eg_net_submit_move(from, to, promo);
}

static void on_mode(int mode)
{
    eg_store_save_mode(mode);
    esp_restart();                         /* every screen is rebuilt with the new colors */
}

static void on_forget(void)
{
    eg_store_clear_token();
    esp_restart();
}

/* ---------- Wi-Fi scan (own task: a scan blocks for a few seconds) ---------- */

static TaskHandle_t scan_task_h;

static void scan_task(void *arg)
{
    (void)arg;
    static eg_ap_t aps[20];
    for (;;) {
        ulTaskNotifyTake(pdTRUE, portMAX_DELAY);
        lvgl_port_lock(0);
        eg_wifi_set_scanning(scr_wifi);
        lvgl_port_unlock();
        int n = eg_bsp_wifi_scan(aps, 20);
        lvgl_port_lock(0);
        eg_wifi_set_networks(scr_wifi, aps, n);
        lvgl_port_unlock();
    }
}

static void request_scan(void)
{
    if (scan_task_h) xTaskNotifyGive(scan_task_h);
}

static void on_wifi_back(void)
{
    want_wifi_back = true;
}

static void on_menu_wifi(void)
{
    want_wifi_screen = true;
}

/* ---------- home navigation (UI task) ----------
 * Sub-screens open instantly from the UI; anything that needs the server becomes a request
 * the network task picks up within 250 ms. */

static struct {
    volatile bool home, ai, challenge, open, set, resign, rank, thumbs, sets, set_edit, poll_now;
    volatile bool qm_join, qm_cancel, search, chal_send, respond, respond_accept;
    char difficulty[16], color[8], game_id[40], set_id[48];
    char query[32], opp_id[40], opp_name[33], first[10], chal_id[40];
    TickType_t search_at;               /* debounce: search when the typing stops for 400 ms */
} req;

static void ui_load(lv_obj_t *s) { lv_screen_load(s); }   /* already in the LVGL task */

static void on_home_play_ai(void) { eg_ai_setup_set_status(scr_ai, NULL); ui_load(scr_ai); }
static void on_home_challenge(void)
{
    eg_challenge_set(scr_chal, NULL, "Making a link...");
    ui_load(scr_chal);
    snprintf(req.color, sizeof req.color, "random");
    req.challenge = true;
}
/* Quick match. Cancel drops a pending join (rapid Quick match, Cancel taps) and goes home at once;
 * the network task cancels the queue entry, and opens the game if a match landed in between. */
static char qm_tc[8] = "10+0";            /* the clock picked for quick match, "" untimed */
static void on_home_quick(void)
{
    eg_qm_pick(scr_qm);
    ui_load(scr_qm);
}
static void on_qm_join(const char *tc)
{
    snprintf(qm_tc, sizeof qm_tc, "%s", tc ? tc : "");
    eg_qm_set(scr_qm, "Looking for an opponent...", true);
    req.qm_join = true;
}
static void on_qm_cancel(void)
{
    req.qm_join = false;
    req.qm_cancel = true;
    behind = scr_home;
    ui_load(scr_home);
}
static void on_qm_retry(void) { on_qm_join(qm_tc); }

/* Challenge a player */
static void on_home_find(void) { eg_find_reset(scr_find); ui_load(scr_find); }
static void on_find_query(const char *q)
{
    snprintf(req.query, sizeof req.query, "%s", q);
    req.search_at = xTaskGetTickCount() + pdMS_TO_TICKS(400);
    req.search = strlen(req.query) >= 3;
}
static char chal_tc[8];
static void on_find_send(const char *id, const char *name, const char *first, const char *time_control)
{
    snprintf(chal_tc, sizeof chal_tc, "%s", time_control ? time_control : "");
    snprintf(req.opp_id, sizeof req.opp_id, "%s", id);
    snprintf(req.opp_name, sizeof req.opp_name, "%s", name[0] ? name : "them");
    snprintf(req.first, sizeof req.first, "%s", first);
    req.chal_send = true;
}
static void on_respond(const char *id, bool accept)
{
    snprintf(req.chal_id, sizeof req.chal_id, "%s", id);
    req.respond_accept = accept;
    req.respond = true;
}

static void on_tab(int tab)
{
    lv_obj_t *screens[4] = {scr_home, scr_sets, scr_rank, scr_you};
    if (tab < 0 || tab > 3) return;
    if (tab == 1) { eg_sets_set(scr_sets, &home); req.sets = true; }
    if (tab == 2) req.rank = true;
    if (tab == 3) eg_you_set(scr_you, &home);
    if (tab == 0) req.home = true;
    behind = screens[tab];                 /* Wi-Fi's Back returns here */
    ui_load(screens[tab]);
}
static void on_make(void) { ui_load(scr_make); }
static void on_make_back(void) { req.sets = true; behind = scr_sets; ui_load(scr_sets); }   /* a new set may be ready */
static void on_home_open(const char *id) { snprintf(req.game_id, sizeof req.game_id, "%s", id); req.open = true; }
static void on_sub_back(void) { req.search = false; req.home = true; behind = scr_home; ui_load(scr_home); }
static void on_chal_back(void) { ui_load(scr_find); }   /* Send a link was opened from Challenge a player */
static void on_ai_start(const char *difficulty, const char *color)
{
    snprintf(req.difficulty, sizeof req.difficulty, "%s", difficulty);
    snprintf(req.color, sizeof req.color, "%s", color);
    req.ai = true;
}
static void on_pick_set(const char *id) { snprintf(req.set_id, sizeof req.set_id, "%s", id); req.set = true; }
static char set_edit_id[48], set_edit_name[40];
static bool set_edit_delete;
static void on_set_rename(const char *id, const char *name)
{
    snprintf(set_edit_id, sizeof set_edit_id, "%s", id);
    snprintf(set_edit_name, sizeof set_edit_name, "%s", name);
    set_edit_delete = false;
    req.set_edit = true;
}
static void on_set_delete(const char *id)
{
    snprintf(set_edit_id, sizeof set_edit_id, "%s", id);
    set_edit_delete = true;
    req.set_edit = true;
}
static void on_clock_zero(void) { req.poll_now = true; }
static void on_menu_home(void) { req.home = true; ui_load(scr_home); }
static void on_resign(void) { req.resign = true; }

/* ---------- power and notifications (UI task) ----------
 * Dim to 20% after 2 minutes untouched, backlight off after 10. The first touch on a dark screen only
 * wakes it. Never dark while it's your move in a timed game. No speaker, so notifications are visual:
 * a dot on Play, a banner at the top, and a dark screen lights up for 60 s. */

#define DIM_MS (2 * 60 * 1000)
#define OFF_MS (10 * 60 * 1000)
#define NOTIFY_AWAKE_MS (60 * 1000)

static volatile bool keep_awake;          /* set by the network task */
static int bl_now = -1;
static lv_obj_t *catcher, *banner;
static bool notify_woke;
static char banner_game[40];
static bool banner_is_challenge;

static void backlight(int pct)
{
    if (pct == bl_now) return;
    bl_now = pct;
    eg_bsp_backlight((uint8_t)pct);
}

static void catcher_cb(lv_event_t *e)
{
    lv_event_code_t c = lv_event_get_code(e);
    if (c == LV_EVENT_PRESSED) { backlight(100); notify_woke = false; }
    else if (c == LV_EVENT_CLICKED || c == LV_EVENT_PRESS_LOST) {
        lv_obj_delete_async(catcher);
        catcher = NULL;
    }
}

static void go_dark(void)
{
    backlight(0);
    notify_woke = false;
    if (catcher) return;
    catcher = lv_obj_create(lv_layer_top());           /* eats the waking touch */
    lv_obj_remove_style_all(catcher);
    lv_obj_set_size(catcher, 800, 480);
    lv_obj_add_flag(catcher, LV_OBJ_FLAG_CLICKABLE);
    lv_obj_add_event_cb(catcher, catcher_cb, LV_EVENT_ALL, NULL);
}

static void power_tick(lv_timer_t *t)
{
    (void)t;
    uint32_t idle = lv_display_get_inactive_time(NULL);
    if (catcher && bl_now == 0) {                       /* dark: stay dark until touched or notified */
        if (keep_awake) { lv_obj_delete(catcher); catcher = NULL; backlight(100); }
        return;
    }
    if (notify_woke) {
        if (idle < 1000) notify_woke = false;           /* someone touched it: normal rules again */
        else if (idle > NOTIFY_AWAKE_MS) { go_dark(); return; }
        else { backlight(100); return; }
    }
    if (keep_awake || idle < DIM_MS) backlight(100);
    else if (idle < OFF_MS) backlight(20);
    else go_dark();
}

static void banner_close(void)
{
    if (banner) { lv_obj_delete(banner); banner = NULL; }
}
static void banner_x_cb(lv_event_t *e) { (void)e; banner_close(); }
static void banner_open_cb(lv_event_t *e)
{
    (void)e;
    if (banner_is_challenge || !banner_game[0]) { req.home = true; behind = scr_home; ui_load(scr_home); }
    else { snprintf(req.game_id, sizeof req.game_id, "%s", banner_game); req.open = true; }
    banner_close();
}
static void banner_timeout(lv_timer_t *t) { (void)t; banner_close(); }
static void banner_y(void *o, int32_t v) { lv_obj_set_y(o, v); }

/* Call with the LVGL lock held. */
static void notify(const char *text, const char *game_id, bool challenge)
{
    banner_close();
    snprintf(banner_game, sizeof banner_game, "%s", game_id ? game_id : "");
    banner_is_challenge = challenge;
    banner = lv_obj_create(lv_layer_top());
    lv_obj_remove_flag(banner, LV_OBJ_FLAG_SCROLLABLE);
    lv_obj_add_flag(banner, LV_OBJ_FLAG_CLICKABLE);
    lv_obj_set_size(banner, 800, 64);
    lv_obj_set_pos(banner, 0, -64);
    lv_obj_set_style_bg_color(banner, EG_BG_VOID, 0);
    lv_obj_set_style_radius(banner, 0, 0);
    lv_obj_set_style_border_width(banner, 3, 0);
    lv_obj_set_style_border_side(banner, LV_BORDER_SIDE_BOTTOM, 0);
    lv_obj_set_style_border_color(banner, challenge ? EG_CYAN : EG_PINK, 0);
    lv_obj_set_style_pad_all(banner, 0, 0);
    lv_obj_t *dot = lv_obj_create(banner);
    lv_obj_remove_style_all(dot);
    lv_obj_set_size(dot, 14, 14);
    lv_obj_set_style_radius(dot, LV_RADIUS_CIRCLE, 0);
    lv_obj_set_style_bg_color(dot, challenge ? EG_CYAN : EG_PINK, 0);
    lv_obj_set_style_bg_opa(dot, LV_OPA_COVER, 0);
    lv_obj_align(dot, LV_ALIGN_LEFT_MID, 24, 0);
    lv_obj_t *l = lv_label_create(banner);
    lv_obj_set_style_text_font(l, &eg_sora_20_bold, 0);
    lv_obj_set_style_text_color(l, EG_FG, 0);
    lv_label_set_long_mode(l, LV_LABEL_LONG_DOT);
    lv_obj_set_width(l, 560);
    lv_label_set_text(l, text);
    lv_obj_align(l, LV_ALIGN_LEFT_MID, 52, 0);
    lv_obj_t *hint = lv_label_create(banner);
    lv_obj_set_style_text_font(hint, &eg_sora_16, 0);
    lv_obj_set_style_text_color(hint, EG_FG_HAZE, 0);
    lv_label_set_text(hint, "Tap to open");
    lv_obj_align(hint, LV_ALIGN_RIGHT_MID, -84, 0);
    lv_obj_t *x = lv_button_create(banner);
    lv_obj_set_size(x, 56, 44);
    lv_obj_align(x, LV_ALIGN_RIGHT_MID, -12, 0);
    lv_obj_set_style_bg_color(x, EG_SURFACE, 0);
    lv_obj_set_style_radius(x, LV_RADIUS_CIRCLE, 0);
    lv_obj_set_style_shadow_width(x, 0, 0);
    lv_obj_t *xl = lv_label_create(x);
    lv_obj_set_style_text_font(xl, &lv_font_montserrat_20, 0);
    lv_obj_set_style_text_color(xl, EG_FG, 0);
    lv_label_set_text(xl, LV_SYMBOL_CLOSE);
    lv_obj_center(xl);
    lv_obj_add_event_cb(x, banner_x_cb, LV_EVENT_CLICKED, NULL);
    lv_obj_add_event_cb(banner, banner_open_cb, LV_EVENT_CLICKED, NULL);
    lv_anim_t a;
    lv_anim_init(&a);
    lv_anim_set_var(&a, banner);
    lv_anim_set_exec_cb(&a, banner_y);
    lv_anim_set_values(&a, -64, 0);
    lv_anim_set_duration(&a, 260);
    lv_anim_set_path_cb(&a, lv_anim_path_ease_out);
    lv_anim_start(&a);
    lv_timer_t *t = lv_timer_create(banner_timeout, NOTIFY_AWAKE_MS, NULL);
    lv_timer_set_repeat_count(t, 1);
    if (catcher) { lv_obj_delete(catcher); catcher = NULL; }   /* a dark screen lights up */
    if (bl_now != 100) { backlight(100); notify_woke = true; }
}

/* What's waiting for you (games against people where it's your move, and challenges), compared
 * with the last home refresh. Network task. */
static char seen[EG_HOME_MAX_GAMES + EG_HOME_MAX_INCOMING][40];
static int seen_n = -1;                    /* -1: first refresh after boot, nothing is "new" */

static void check_waiting(const eg_home_t *h)
{
    char now_ids[EG_HOME_MAX_GAMES + EG_HOME_MAX_INCOMING][40];
    int n = 0;
    const char *new_text = NULL, *new_game = NULL;
    bool new_chal = false;
    static char text[96];
    int new_count = 0;
    for (int i = 0; i < h->n_incoming; i++) snprintf(now_ids[n++], 40, "%s", h->incoming[i].id);
    for (int i = 0; i < h->n_games; i++)
        if (h->games[i].your_turn && !h->games[i].opponent_ai) snprintf(now_ids[n++], 40, "%s", h->games[i].id);
    if (seen_n >= 0) {
        for (int i = 0; i < n; i++) {
            bool was = false;
            for (int k = 0; k < seen_n; k++) if (strcmp(seen[k], now_ids[i]) == 0) was = true;
            if (was) continue;
            new_count++;
            if (new_text) continue;
            if (i < h->n_incoming) {
                const eg_incoming_t *c = &h->incoming[i];
                snprintf(text, sizeof text, "%s challenged you", c->name[0] ? c->name : "Someone");
                new_chal = true;
            } else {
                for (int g = 0; g < h->n_games; g++)
                    if (strcmp(h->games[g].id, now_ids[i]) == 0) {
                        snprintf(text, sizeof text, "Your move against %s", h->games[g].opponent[0] ? h->games[g].opponent : "your opponent");
                        new_game = h->games[g].id;
                    }
            }
            new_text = text;
        }
    }
    if (new_count > 1) snprintf(text, sizeof text, "%d games and challenges are waiting for you", new_count);
    memcpy(seen, now_ids, sizeof now_ids[0] * n);
    seen_n = n;
    lvgl_port_lock(0);
    eg_screens_set_badge(n > 0);
    if (new_text) notify(text, new_count > 1 ? NULL : new_game, new_count > 1 || new_chal);
    lvgl_port_unlock();
}

/* ---------- network task ---------- */

static struct { bool pending; char from[3], to[3], promo; } mailbox;

void eg_net_submit_move(const char *from, const char *to, char promo)
{
    memcpy(mailbox.from, from, 3);
    memcpy(mailbox.to, to, 3);
    mailbox.promo = promo;
    mailbox.pending = true;
}

static void apply_game(const eg_game_t *g)
{
    cur = *g;
    have_game = true;
    lvgl_port_lock(0);
    eg_game_set(scr_game, g);
    behind = scr_game;
    if (!wifi_open) lv_screen_load(scr_game);
    bool need_pic = !g->opp_ai && g->opp_pfp[0] && !eg_avatar_find(g->opp_pfp, EG_GAME_AVATAR_PX);
    lvgl_port_unlock();
    if (need_pic && eg_avatar_load(g->opp_pfp, EG_GAME_AVATAR_PX)) {     /* the board shows first, the picture follows */
        lvgl_port_lock(0); eg_game_refresh_avatar(scr_game); lvgl_port_unlock();
    }
}

/* Your picture for You: fetched once per URL. Network task. */
static void load_you_pic(void)
{
    if (home.pfp[0] && !eg_avatar_find(home.pfp, EG_YOU_AVATAR_PX)) {
        eg_avatar_load(home.pfp, EG_YOU_AVATAR_PX);
        eg_avatar_load(home.pfp, EG_GAME_AVATAR_PX);
        lvgl_port_lock(0); eg_you_set(scr_you, &home); lvgl_port_unlock();
    }
    lvgl_port_lock(0); eg_game_set_you(scr_game, home.name, home.pfp); lvgl_port_unlock();
}

static void handle_wifi(void);

static bool pair(void)
{
    eg_pairing_t p;
    show_main(scr_pair);
    while (eg_api_pair_start(&p) != EG_OK) {
        for (int i = 0; i < 20; i++) { vTaskDelay(pdMS_TO_TICKS(250)); handle_wifi(); }
    }
    lvgl_port_lock(0);
    eg_pair_set_code(scr_pair, p.code, p.claim_url[0] ? p.claim_url : NULL);
    lvgl_port_unlock();
    for (;;) {
        for (int i = 0; i < 12; i++) { vTaskDelay(pdMS_TO_TICKS(250)); handle_wifi(); }
        eg_result_t r = eg_api_pair_poll(p.poll_secret, token);
        if (r == EG_OK) { eg_store_save_token(token); return true; }
        if (r == EG_EXPIRED) return false;      /* caller starts over with a fresh code */
    }
}

static void wifi_error(const char *msg)
{
    lvgl_port_lock(0);
    eg_wifi_set_error(scr_wifi, msg);
    lvgl_port_unlock();
}

/* Try the typed credentials. Saves them only if they work. */
static bool try_pending_creds(void)
{
    creds_pending = false;
    if (eg_bsp_wifi_connect(want_ssid, want_pass, 20000)) {
        eg_store_save_wifi(want_ssid, want_pass);
        wifi_error(NULL);
        return true;
    }
    wifi_error("Couldn't connect. Check the password.");
    if (wifi_open) {                      /* switching from a working network: get back on it meanwhile */
        char ssid[33] = {0}, pass[65] = {0};
        if (eg_store_load_wifi(ssid, pass) && ssid[0]) eg_bsp_wifi_connect(ssid, pass, 20000);
    }
    return false;
}

/* Wi-Fi screen opened from a main screen: Back, or a new network that works, returns there. */
static void handle_wifi(void)
{
    if (want_wifi_screen) {
        want_wifi_screen = false;
        wifi_open = true;
        lvgl_port_lock(0);
        eg_wifi_set_back_visible(scr_wifi, true);
        eg_wifi_set_error(scr_wifi, NULL);
        lv_screen_load(scr_wifi);
        lvgl_port_unlock();
        request_scan();
    }
    if (want_wifi_back) {
        want_wifi_back = false;
        if (wifi_open) { wifi_open = false; if (behind) show(behind); }
    }
    if (creds_pending && wifi_open) {
        if (try_pending_creds()) { wifi_open = false; if (behind) show(behind); }
    }
}
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
void app_main(void)
{
    esp_err_t e = nvs_flash_init();
    if (e == ESP_ERR_NVS_NO_FREE_PAGES || e == ESP_ERR_NVS_NEW_VERSION_FOUND) { nvs_flash_erase(); nvs_flash_init(); }

    eg_theme_init((eg_mode_t)eg_store_load_mode());   /* colors first: every screen reads them */
    if (!eg_bsp_init()) { ESP_LOGE(TAG, "display init failed"); return; }
    lvgl_port_lock(0);
    scr_boot = eg_boot_create(NULL);          /* something on screen right away */
    lv_screen_load(scr_boot);
    lvgl_port_unlock();

    /* LVGL's 256 KB pool is too small for every screen plus piece decoding: give it 8 MB of PSRAM. */
    {
        const size_t extra = 8 * 1024 * 1024;
        void *pool = heap_caps_malloc(extra, MALLOC_CAP_SPIRAM);
        lvgl_port_lock(0);
        if (!pool) ESP_LOGW(TAG, "no PSRAM for the LVGL pool");
        else if (!lv_mem_add_pool(pool, extra)) { ESP_LOGE(TAG, "LVGL refused the extra pool"); heap_caps_free(pool); }
        else ESP_LOGI(TAG, "LVGL pool +%u KB", (unsigned)(extra / 1024));
        lvgl_port_unlock();
    }

    lvgl_port_lock(0);
    scr_wifi = eg_wifi_create(NULL, on_wifi_connect, request_scan, on_wifi_back);
    eg_screens_set_wifi_handler(on_menu_wifi);
    scr_pair = eg_pair_create(NULL);
    eg_screens_set_tab_handler(on_tab);
    eg_home_cb_t hcb = {.on_play_ai = on_home_play_ai, .on_challenge = on_home_challenge, .on_open_game = on_home_open,
                        .on_quick_match = on_home_quick, .on_find_player = on_home_find, .on_respond = on_respond};
    scr_home = eg_home_create(NULL, &hcb);
    scr_ai = eg_ai_setup_create(NULL, on_ai_start, on_sub_back);
    scr_chal = eg_challenge_create(NULL, on_chal_back);
    scr_qm = eg_qm_create(NULL, on_qm_join, on_qm_cancel, on_qm_retry);
    eg_find_cb_t fcb = {.on_query = on_find_query, .on_send = on_find_send, .on_link = on_home_challenge, .on_back = on_sub_back};
    scr_find = eg_find_create(NULL, &fcb);
    scr_sets = eg_sets_create(NULL, on_pick_set, on_make);
    scr_make = eg_make_create(NULL, on_make_back);
    eg_sets_set_edit(scr_sets, on_set_rename, on_set_delete);
    scr_rank = eg_rank_create(NULL);
    scr_you = eg_you_create(NULL, on_forget, eg_ota_version());
    eg_you_set_mode_handler(scr_you, on_mode);
    eg_game_cb_t cb = {.on_move = on_move, .on_resign = on_resign, .on_menu_home = on_menu_home, .on_clock_zero = on_clock_zero};
    scr_game = eg_game_create(NULL, &cb);
    lv_timer_create(power_tick, 500, NULL);
    lvgl_port_unlock();
    xTaskCreate(scan_task, "scan", 10 * 1024, NULL, 4, &scan_task_h);
    xTaskCreate(net_task, "net", 16 * 1024, NULL, 5, NULL);
}

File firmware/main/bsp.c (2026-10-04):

/* SPDX-License-Identifier: MIT */
/* Board support for the Elecrow CrowPanel Advanced 5" ESP32-P4 (SKU DHE04005D, PCB V1.0).
 * The only hardware-specific file. Everything else (UI, API, storage) is board independent.
 *
 * Hardware facts (from Elecrow's published schematics and sample firmware for this board):
 *   Power      LDO channel 3 = 2.5 V, LDO channel 4 = 3.3 V (feed the panel and peripherals)
 *   I2C        port 0, SDA GPIO45, SCL GPIO46, internal pull-ups. Shared by touch and the backlight MCU
 *   Backlight  STC8H1K MCU at I2C 0x2F. Register 0x20 = backlight PWM duty, 0..100
 *   Touch      GT911 on the shared I2C bus, RST GPIO36, INT GPIO42
 *   Display    16-bit RGB565 parallel, 800x480, PCLK 25 MHz on GPIO3, DE GPIO2, HSYNC GPIO40, VSYNC GPIO41
 *              data D0..D15 = GPIO 8,7,6,5,4,14,13,12,11,10,9,19,18,17,16,15
 *              timing: HSYNC 4, HBP 8, HFP 8, VSYNC 4, VBP 16, VFP 16; data latched on PCLK falling edge
 *   Wi-Fi      onboard ESP32-C6 over SDIO slot 1 (4-bit): CMD 54, CLK 53, D0 52, D1 51, D2 50, D3 49,
 *              C6 reset GPIO20 (active high). Configured in sdkconfig.defaults; the standard esp_wifi API
 *              is provided by esp_wifi_remote + esp_hosted.
 */
#include "bsp.h"

#include <string.h>
#include <stdlib.h>
#include "esp_log.h"
#include "esp_check.h"
#include "esp_ldo_regulator.h"
#include "driver/i2c_master.h"
#include "esp_lcd_panel_rgb.h"
#include "esp_lcd_panel_ops.h"
#include "esp_lcd_panel_io.h"
#include "esp_lcd_touch_gt911.h"
#include "esp_lvgl_port.h"
#include "esp_wifi.h"
#include "esp_event.h"
#include "esp_netif.h"
#include "freertos/event_groups.h"
#include "freertos/semphr.h"

static const char *TAG = "eg_bsp";

#define EG_H_RES 800
#define EG_V_RES 480

#define EG_I2C_SDA 45
#define EG_I2C_SCL 46
#define EG_TOUCH_RST 36
#define EG_TOUCH_INT 42

#define EG_BL_MCU_ADDR 0x2F
#define EG_BL_REG_PWM 0x20

static esp_ldo_channel_handle_t s_ldo3, s_ldo4;
static i2c_master_bus_handle_t s_i2c;
static i2c_master_dev_handle_t s_bl_dev;
static esp_lcd_panel_handle_t s_panel;
static esp_lcd_touch_handle_t s_touch;
static lv_display_t *s_disp;

static esp_err_t power_init(void)
{
    esp_ldo_channel_config_t ldo3 = {.chan_id = 3, .voltage_mv = 2500};
    esp_ldo_channel_config_t ldo4 = {.chan_id = 4, .voltage_mv = 3300};
    ESP_RETURN_ON_ERROR(esp_ldo_acquire_channel(&ldo3, &s_ldo3), TAG, "ldo3");
    ESP_RETURN_ON_ERROR(esp_ldo_acquire_channel(&ldo4, &s_ldo4), TAG, "ldo4");
    return ESP_OK;
}

static esp_err_t i2c_init(void)
{
    i2c_master_bus_config_t cfg = {
        .i2c_port = 0,
        .sda_io_num = EG_I2C_SDA,
        .scl_io_num = EG_I2C_SCL,
        .clk_source = I2C_CLK_SRC_DEFAULT,
        .glitch_ignore_cnt = 7,
        .flags.enable_internal_pullup = true,
    };
    ESP_RETURN_ON_ERROR(i2c_new_master_bus(&cfg, &s_i2c), TAG, "i2c bus");
    i2c_device_config_t bl = {.dev_addr_length = I2C_ADDR_BIT_LEN_7, .device_address = EG_BL_MCU_ADDR, .scl_speed_hz = 100000};
    ESP_RETURN_ON_ERROR(i2c_master_bus_add_device(s_i2c, &bl, &s_bl_dev), TAG, "backlight mcu");
    return ESP_OK;
}

void eg_bsp_backlight(uint8_t percent)
{
    if (!s_bl_dev) return;
    if (percent > 100) percent = 100;
    uint8_t buf[2] = {EG_BL_REG_PWM, percent};
    esp_err_t e = i2c_master_transmit(s_bl_dev, buf, sizeof(buf), 100);
    if (e != ESP_OK) ESP_LOGW(TAG, "backlight write failed: %s", esp_err_to_name(e));
}

static esp_err_t touch_init(void)
{
    esp_lcd_panel_io_handle_t io = NULL;
    esp_lcd_panel_io_i2c_config_t io_cfg = ESP_LCD_TOUCH_IO_I2C_GT911_CONFIG();
    io_cfg.scl_speed_hz = 400000;
    ESP_RETURN_ON_ERROR(esp_lcd_new_panel_io_i2c(s_i2c, &io_cfg, &io), TAG, "touch io");
    esp_lcd_touch_config_t cfg = {
        .x_max = EG_H_RES,
        .y_max = EG_V_RES,
        .rst_gpio_num = EG_TOUCH_RST,
        .int_gpio_num = EG_TOUCH_INT,
        .levels = {.reset = 0, .interrupt = 0},
        .flags = {.swap_xy = 0, .mirror_x = 0, .mirror_y = 0},
    };
    return esp_lcd_touch_new_i2c_gt911(io, &cfg, &s_touch);
}

static esp_err_t panel_init(void)
{
    esp_lcd_rgb_panel_config_t cfg = {
        .clk_src = LCD_CLK_SRC_DEFAULT,
        .data_width = 16,
        .bits_per_pixel = 16,
        .num_fbs = 1,                       /* one frame buffer in PSRAM; LVGL draws partial areas into it */
        .dma_burst_size = 64,
        .disp_gpio_num = -1,
        .pclk_gpio_num = 3,
        .vsync_gpio_num = 41,
        .hsync_gpio_num = 40,
        .de_gpio_num = 2,
        .data_gpio_nums = {8, 7, 6, 5, 4, 14, 13, 12, 11, 10, 9, 19, 18, 17, 16, 15},
        .timings = {
            .pclk_hz = 25 * 1000 * 1000,
            .h_res = EG_H_RES,
            .v_res = EG_V_RES,
            .hsync_pulse_width = 4,
            .hsync_back_porch = 8,
            .hsync_front_porch = 8,
            .vsync_pulse_width = 4,
            .vsync_back_porch = 16,
            .vsync_front_porch = 16,
            .flags = {.pclk_active_neg = true, .pclk_idle_high = true},
        },
        .flags.fb_in_psram = true,
    };
    ESP_RETURN_ON_ERROR(esp_lcd_new_rgb_panel(&cfg, &s_panel), TAG, "rgb panel");
    ESP_RETURN_ON_ERROR(esp_lcd_panel_reset(s_panel), TAG, "panel reset");
    ESP_RETURN_ON_ERROR(esp_lcd_panel_init(s_panel), TAG, "panel init");
    return ESP_OK;
}
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

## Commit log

2026-10-03 Scaffold Endgames Board: licenses, trademark policy, device API v1 spec, build guide
    Claude-Session: https://claude.ai/code/session_01Gnhj5RxbNdP1QZj8AQnsMX
2026-10-04 Reference board: CrowPanel Advanced 5in ESP32-P4 touchscreen; API adds legalMoves
    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
2026-10-04 protocol: add GET /board-pieces (additive, v1)
2026-10-04 firmware: LVGL UI, API client, pairing, storage, desktop preview
    Game screen matches the website v2 look: theme.h generated from v2.css, Sora/VT323/Bungee
    fonts (OFL), pieces from board-pieces. bsp.c (display/touch/Wi-Fi bring-up) still needs the board.
    Desktop preview renders the real UI code to docs/screenshots.
2026-10-04 preview: vinyl pieces, website board frame, pink last-move highlight
2026-10-04 hardware: reference board measurements
    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
2026-10-04 hardware: test-fit plate for hole positions
    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
    [test-fit-plate.scad, test-fit-plate.stl]
2026-10-04 hardware: drop case-shape note (Rena's call)
    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
2026-10-04 hardware: case v0, flat brick (tray + lid)
    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
    [case-lid.stl, case-tray.stl]
2026-10-04 hardware: fast test-fit tray for port and post checks
    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
    [test-fit-tray.stl]
2026-10-04 hardware: flat template to check corner holes and USB-C ports
    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
    [template.stl]
2026-10-04 hardware: power button on IO29
    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
2026-10-04 hardware: power slider extender; case exposes only the lower USB-C
    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
    [case-tray.stl, power-slider-extender.stl, test-fit-tray.stl]
2026-10-04 hardware: fix heights and edge clearances from side photo
    Nub tip 5.1 mm (not 7.1), USB-C overhang ~1 mm, 5V-in connector overhang ~5 mm.
    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
    [case-lid.stl, case-tray.stl, power-slider-extender.stl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]
2026-10-04 hardware: no cutout for the 5V connector; template checks only the USB-C the case uses
    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
    [template.stl]
2026-10-04 hardware: template gets the power slider slot
    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
    [template.stl]
2026-10-04 hardware: case files without the 5V connector cutout (previous copy was stale)
    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
    [case-tray.stl, test-fit-tray.stl]
2026-10-04 hardware: template prints the slider extender too; heights account for plate thickness
    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
    [template.stl]
2026-10-04 docs: full build guide and /board page copy
    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
2026-10-04 hardware: use Elecrow's Eagle board file for exact holes, ports, switch; M3 screws
    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
    [case-lid.stl, case-tray.stl, power-slider-extender.stl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]
2026-10-04 firmware: implement bsp.c for CrowPanel Advanced 5in; builds on ESP-IDF 5.5.1
    Screen, touch, backlight (STC8 at 0x2F), Wi-Fi via C6 (SDIO, reset GPIO20).
    Fix api.h includes, a snprintf buffer, font include define; 6 MB app partition.
    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
    [partitions.csv]
2026-10-04 template: mirror for screen-down fit (first print was backwards)
    [template.stl]
2026-10-04 case: M3 hole sizes (board holes measured 3.39 mm)
    [case-lid.stl, case-tray.stl, test-fit-tray.stl]
2026-10-04 holes: use caliper spacing 127.0 x 73.66 mm
    [case-lid.stl, case-tray.stl, template.stl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]
2026-10-04 measurements: caliper hole spacing
2026-10-04 firmware: optional 180 rotation (menuconfig: Endgames board)
2026-10-04 firmware: pin esp_hosted 2.12.12 (Elecrow's tested host); browser flashing guide
2026-10-04 firmware: fix boot crash (main stack in TCM, esp-idf #19020); 200 MHz PSRAM and Wi-Fi pin settings were silently ignored
2026-10-04 firmware: pairing QR (endgam.es/board/pair?code=...), Wi-Fi connects in place without restart, GT911 init retry
2026-10-04 firmware 0.8.0: over-the-air updates (two app slots, rollback, endgam.es/firmware/board.json manifest)
    [partitions.csv]
2026-10-04 firmware 0.8.1: fix build (forward declaration)
    [main.c]
2026-10-04 API: board-home, board-new-game (computer and challenge), computer games, board-resign, board-set
2026-10-05 firmware 0.10.1: centered board with thin rails, move slide + brighter last-move, your pieces always light, who-goes-first, single Play button until search/quick match
2026-10-05 API.md: board-users, quick match, challenge respond; status lines
2026-10-06 API.md: untimed quick match; move website page copy to the endgames repo
    BOARD-PAGE-COPY.md was copy for the endgam.es page, so it now lives in the website repo (docs/console-page-copy.md).
    Claude-Session: https://claude.ai/code/session_011pW2DU2D9YURvrwcckpwwd
2026-10-06 API.md: board-home stats
2026-10-06 firmware 0.13.0: slim header with Back on every screen, new game panel, boot screen, power and notifications
    - Header: 50 px bar with a Back button and the title on every screen
    - Game: Back and Menu on top, opponent card (Computer, Medium for AI), move list inline, your card
    - Boot: pixel queen spinning, wordmark, status line, shown as soon as the display is up
    - Challenge a player: "Send a link instead" opens the QR; its Back returns to search (no loop); search from 3 letters
    - Quick match: pick a clock first (sends timeControl)
    - Rank: rating in mint; You line in the header
    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
2026-10-06 API.md: sets[].missing, board-set 409, board-users needs 3 characters (#1)
2026-10-06 firmware 0.14.0: display modes, press feedback, game-over card with confetti
    - Colors go through a runtime palette (theme_rt.h): Dark now; Light and Mono switch on in You > Display once the theme export writes EG_LIGHT_* and EG_MONO_*. Changing it saves and restarts.
    - Text on bright fills picks dark or white by contrast (eg_on), so every mode reads
    - Buttons sink a little while pressed
    - Game over: a result card pops in over the board; confetti when you win
    Claude-Session: https://claude.ai/code/session_01Q5nQy63UdwScvAxixpyL1v
2026-10-06 firmware 0.14.1: set rename and delete on (board-set-edit is live); sets with missing pieces can't be picked
    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
    [main.c, ui_screens.c]
